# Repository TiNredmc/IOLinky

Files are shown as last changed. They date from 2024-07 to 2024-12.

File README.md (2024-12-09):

# IOLinky

IOLinky is an attempt to implement an open-source bare-minimum working IO-Link device.
This project is the part of the undergraduate Automation engineering Co-operative education project while working as R&D internship at Delta Electrnics (Thailand) PCL. From King Mongkut's Institute of Technology Ladkrabang (KMITL). 

**WARNING: THIS SOFTWARE IS NOT MEANT TO BE USED IN COMMERCIAL PRODUCT, I, THIPOK JIAMJARAPAN WILL NOT BE RESPONSIBLE FOR ANY FAILURES/MULFUNCTIONS CAUSED BY THE USE OF THIS SOFTWARE (OR ANY MATERIAL OF THIS PROJECT) IN THE COMMERCIAL PRODUCT, ESPECIALLY SAFETY-RELATED PRODUCT. USER WHO INSISTED TO USE THIS SOFTWARE IN COMMERCIAL PRODUCT WILL HAVE TO TAKE ALL THE RISK ON YOUR OWN. GOOD LUCK, YOU HAVE BE WARNED**

The example application of the IOLinky is the 24 to 5 VDC buck converter, with the feature of input and output monitoring plus Efuse (I2t) implementation.

The original goal of IOLinky is to build the bare-minimum IO-Link compatible device. But the software stack is endded up working quite well. This will soon shifted from a single-use code to the library-code approach. Contribution to project are appreciately welcome!

# Acknowledgement 

This project was made possible by the generous support from these great individuals.
 - **Mr. P. Haribabu**, RD Firmware engineer from **Delta Electronics (Thailand) PCL** for the internship opportunity and project supervision. 
 - **Mr. Steve Liang**, Technical engineer from **STMicroelectronics** for the IO-Link technical support. 
 - **Wurth Electronics (Thailand) Co., Ltd** for providing free component samples to be used in this project.  
 - **Assoc.Prof.Dr. Apinai Rerkratn** from Automation engineering department, school of engineering **KMITL**.

# General Info

- COM modes
    - Peak COM3 response time (L6362A + STM32F042) at **```51.2us```** 
	- Peak COM3 response time (L6362A + GD32E230F8 + New UART API) at **```33.0us```**
    - Cycle time is **```20.00ms```**
    - Supported all COM modes. But may have spec unmet
    - COM3 **SPEC MET✔️**  (IOLinky v1.0 only, for now)
    - COM2 **SPEC MET✔️**
    - COM1 **SPEC MET✔️**

- M-sequence types (Code-customizable)
    - ```M_TYPE_0``` in **Startup** and **Pre-operate** mode
    - ```M_TYPE_2_2``` or ```M_TYPE_2_V``` in **Operate** mode

- Page (Direct parameters)
    - Direct parameter 1 with master command for switching between operation mode
    - Read / Write the Direct parameter 2 is supported

- ISDU 
    - Read / Write system command (unused for now)
    - Basic mandatory info such as Product ID and Vendor ID
    - Process Data Input only (M_TYPE_2_2 and M_TYPE_2_V)

- Process Data
    - 16 Bit PD input with ```M_TYPE_2_2```
    - 8 octet PD input with ```M_TYPE_2_V``` (IOLinky v1.0)
    - PD output is not implemented at this time of writing but possible

# TODO
- Code separation as a standalone library

- M-sequence
    - Check Master's CKT

- ISDU
    - Vendor command for fun
    - Data storage feature
    
- Event
    - Implement event/diagnostic feature

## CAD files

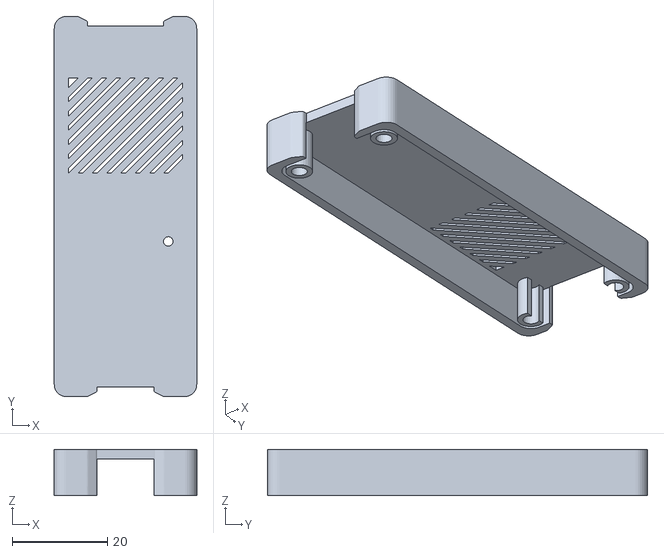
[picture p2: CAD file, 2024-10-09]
Hardware/IOLinky_V1.0/Mechanical/IOLinky_Top_HousingV1.2.stl
30.0 x 80.0 x 9.70

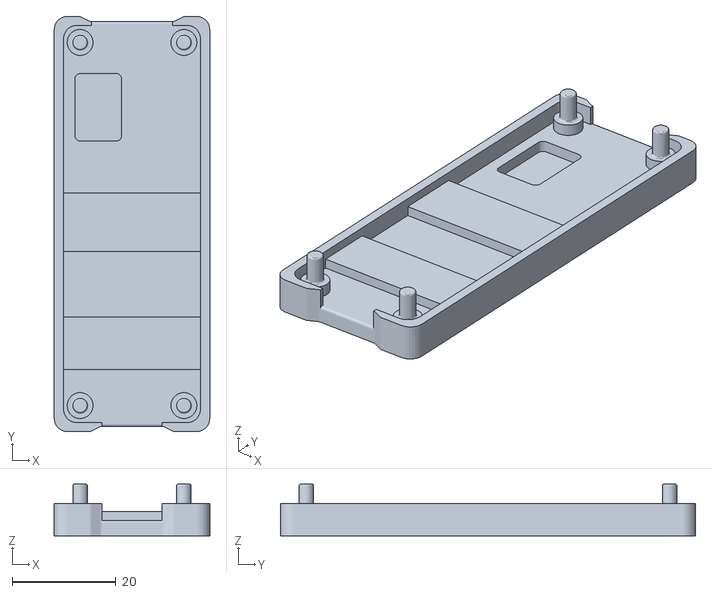
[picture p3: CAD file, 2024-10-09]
Hardware/IOLinky_V1.0/Mechanical/IOLinky_Bottom_HousingV1.2.stl
30.0 x 80.0 x 10.0

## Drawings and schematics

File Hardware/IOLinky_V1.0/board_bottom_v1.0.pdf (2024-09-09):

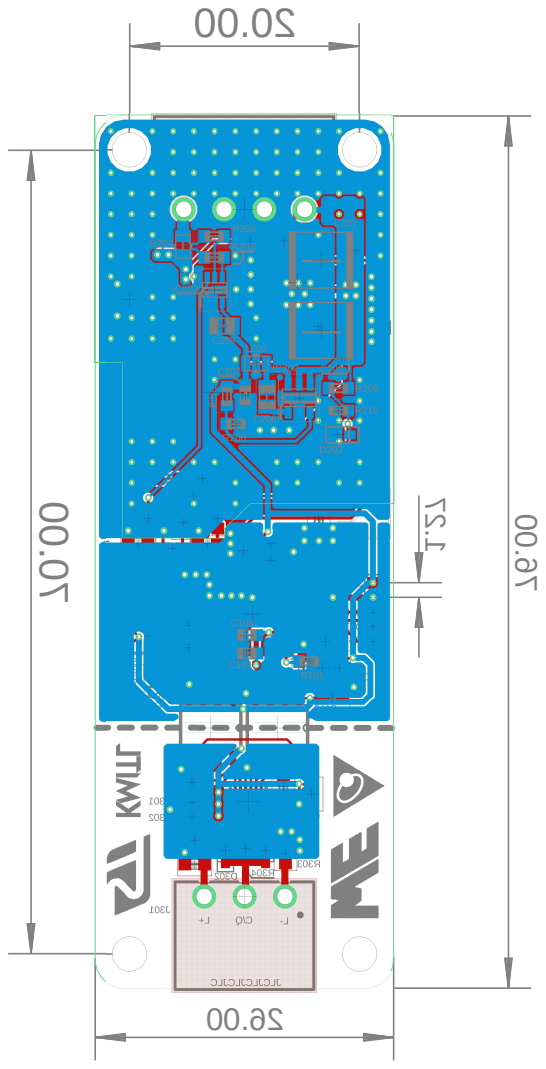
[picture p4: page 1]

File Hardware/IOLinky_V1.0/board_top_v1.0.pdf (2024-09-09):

20.00 70.00

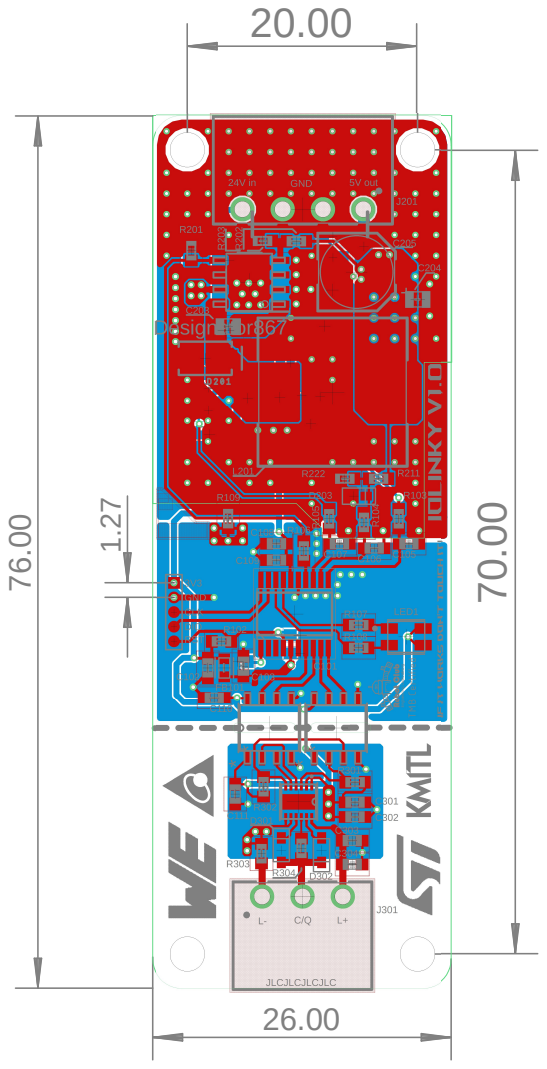
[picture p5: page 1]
Designator867 1.27

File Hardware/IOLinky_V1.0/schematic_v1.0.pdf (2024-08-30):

600R 10k

# FB101 R¹⁰¹

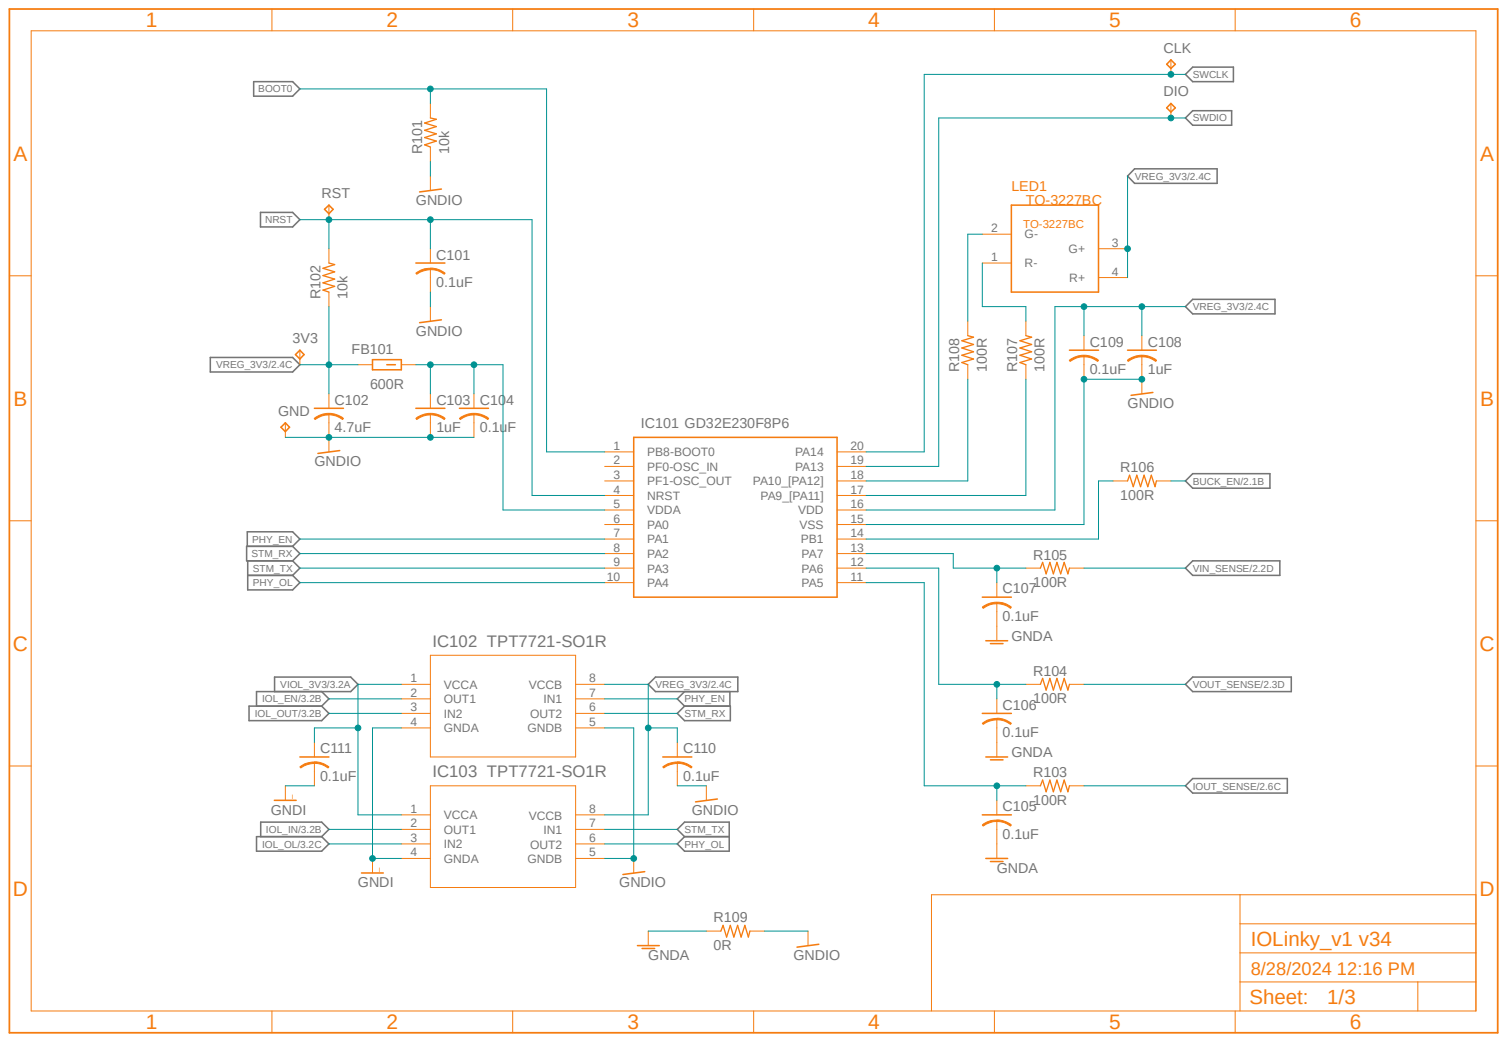
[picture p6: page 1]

A

A

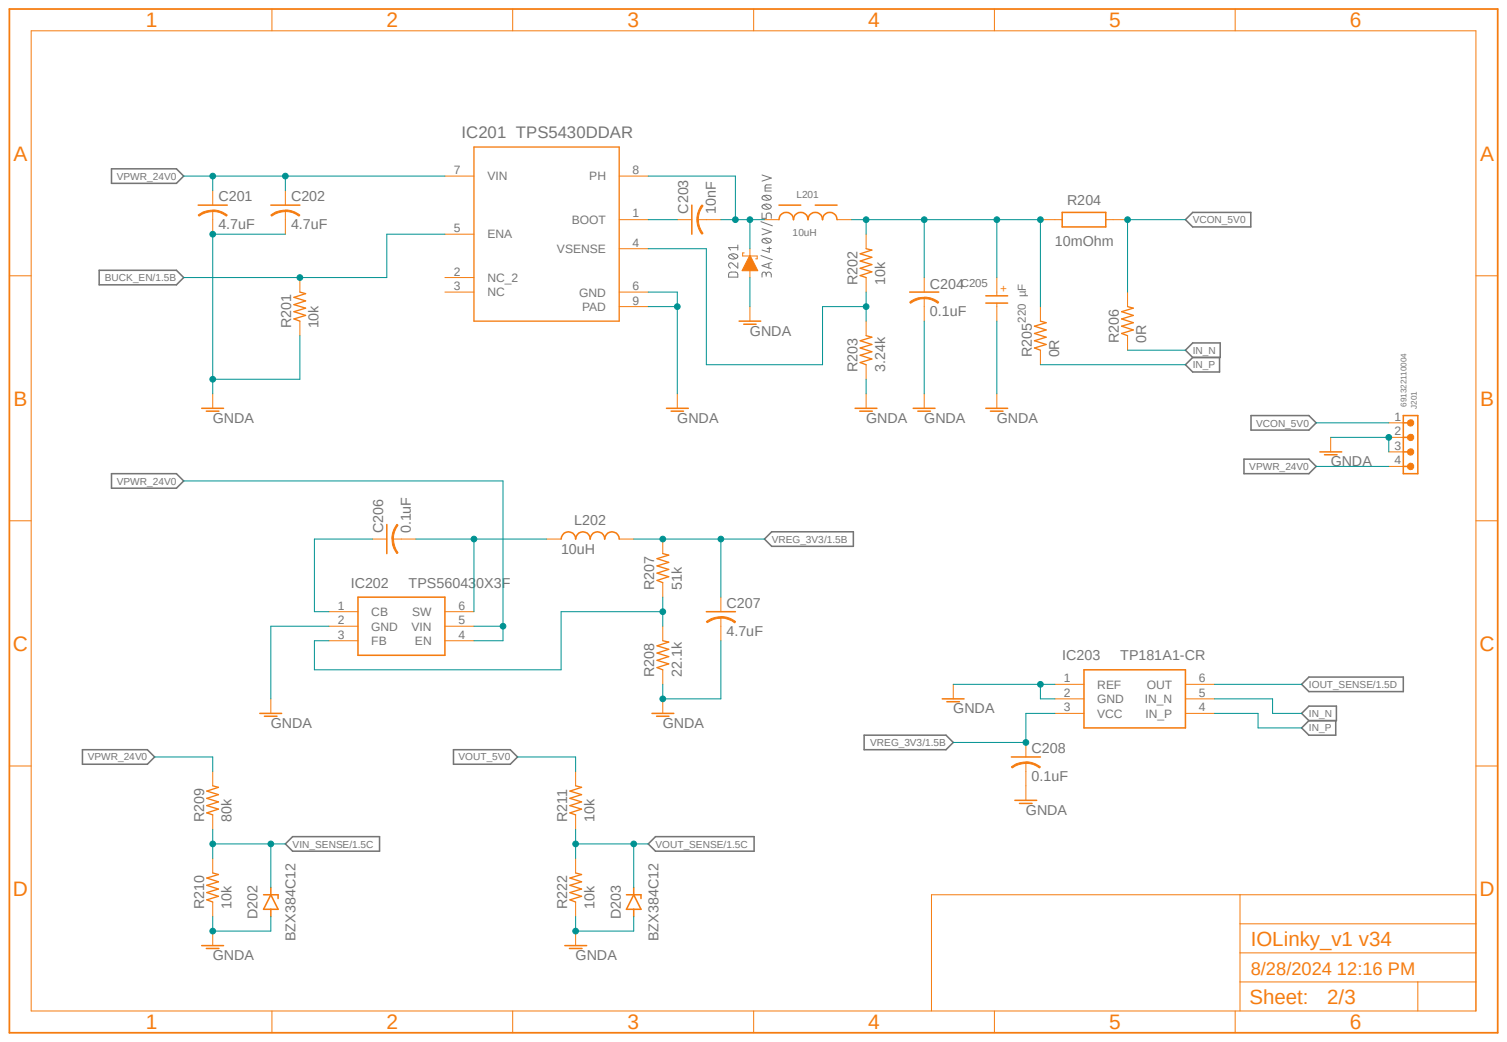
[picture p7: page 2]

A

A

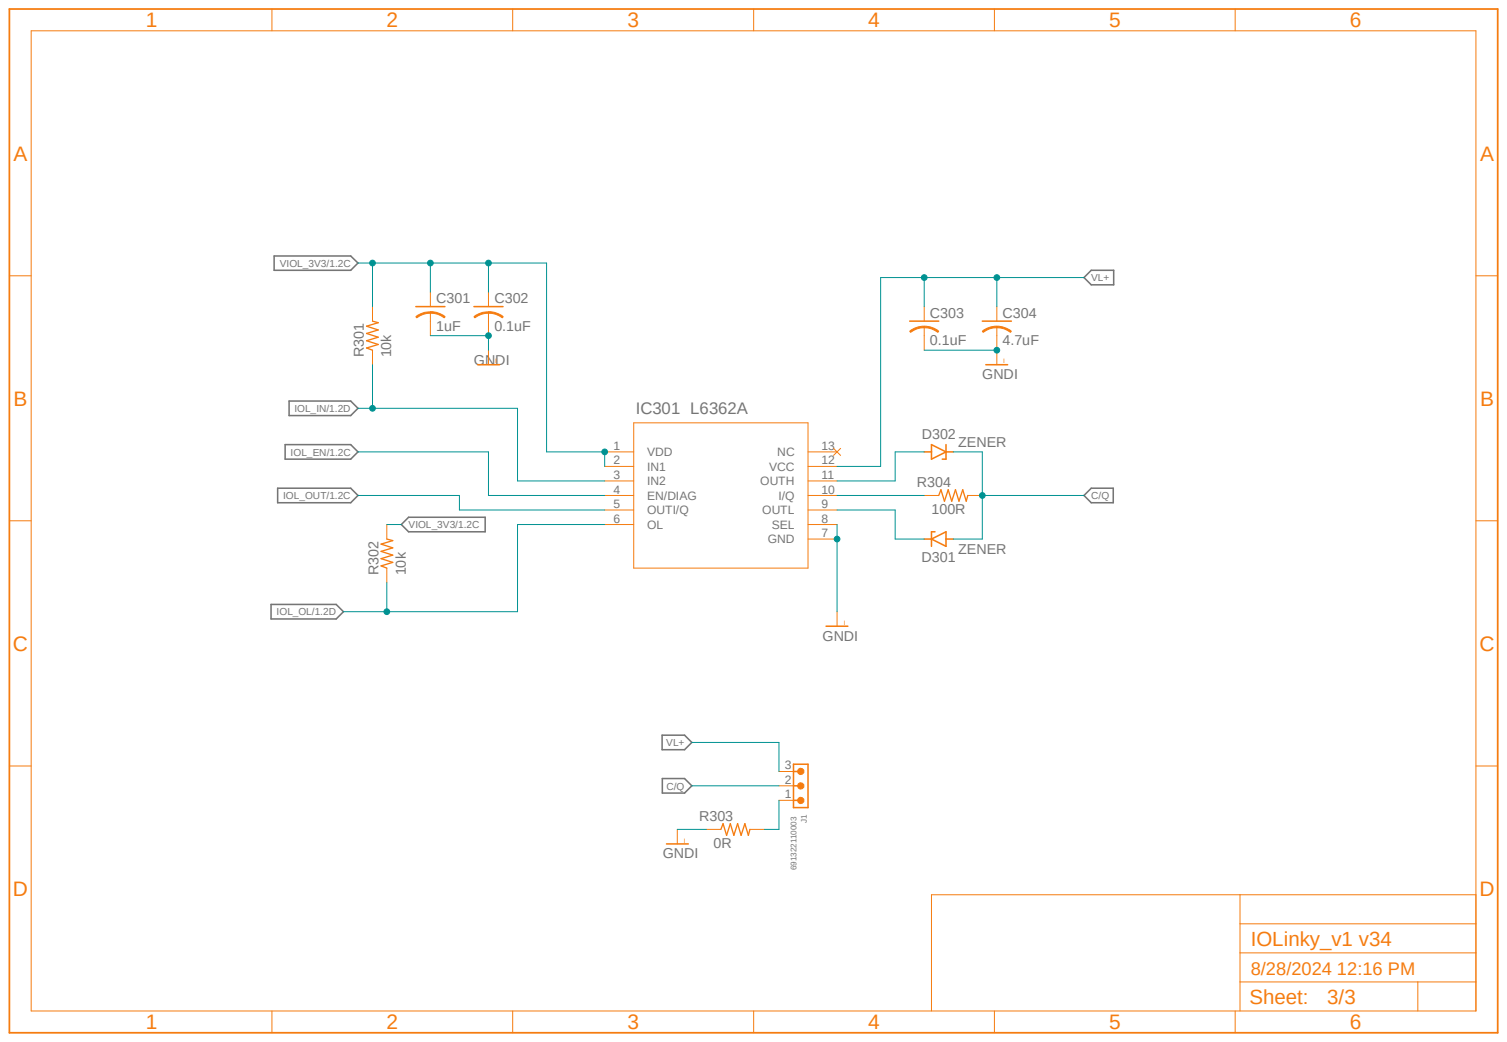
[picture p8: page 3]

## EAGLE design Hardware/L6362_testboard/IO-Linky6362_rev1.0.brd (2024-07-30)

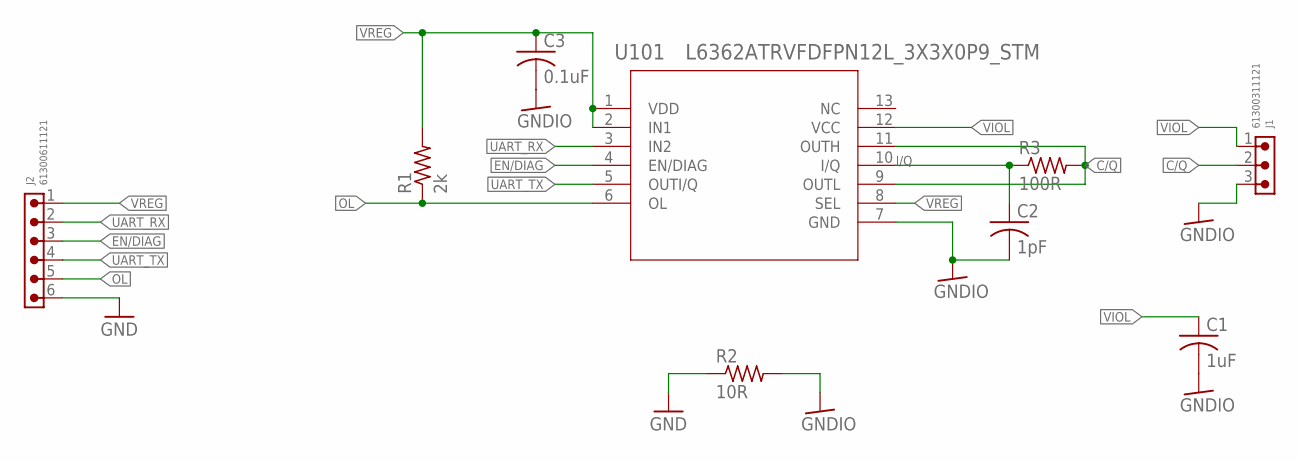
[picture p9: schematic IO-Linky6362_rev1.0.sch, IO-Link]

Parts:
C1: 1uF; C0603K
C2: 1pF; C0603K
C3: 0.1uF; C0603K
J1: 61300311121
J2: 61300611121
R1: 2k; R0603
R2: 10R; R0603
R3: 100R; R0603
U101: L6362ATRVFDFPN12L_3X3X0P9_STM; VFDFPN12L_3X3X0P9_STM

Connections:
C/Q: J1.2, R3.2, U101.9 (OUTL), U101.11 (OUTH)
EN/DIAG: J2.3, U101.4 (EN/DIAG)
GND: J2.6, R2.1
GNDIO: C1.2, C2.2, C3.2, J1.3, R2.2, U101.7 (GND)
I/Q: C2.1, R3.1, U101.10 (I/Q)
OL: J2.5, R1.1, U101.6 (OL)
UART_RX: J2.2, U101.3 (IN2)
UART_TX: J2.4, U101.5 (OUTI/Q)
VIOL: C1.1, J1.1, U101.12 (VCC)
VREG: C3.1, J2.1, R1.2, U101.1 (VDD), U101.2 (IN1), U101.8 (SEL)

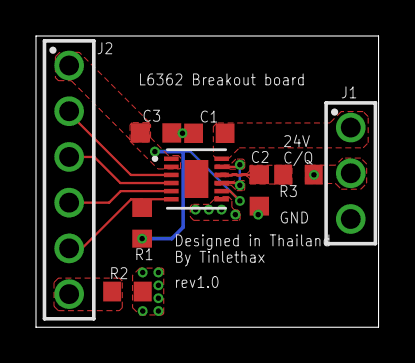
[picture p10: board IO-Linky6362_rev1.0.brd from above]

Board: 2 copper layers, 19.0 x 16.2 mm, 9 parts (0 on the bottom side), 10 nets.

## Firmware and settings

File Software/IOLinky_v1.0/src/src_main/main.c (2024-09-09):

// IO-Linky V1.0 
#include "main.h"

typedef struct myFunctions{
	void (*testA)(void);
	void (*testB)(uint8_t input);
}myFunctions;

void testAFunct(){

}

void testBFunct(uint8_t input){

}

myFunctions testAPI = {
	testAFunct,
	testBFunct
};

void NMI_Handler(void){


}

void HardFault_Handler(void){
	while(1);
}


int main(){
	app_initIO();

	testAPI.testA();
	
	while(1){
		app_runner();
	}


}

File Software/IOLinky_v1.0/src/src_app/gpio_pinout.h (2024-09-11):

#ifndef GPIO_PINOUT_H
#define GPIO_PINOUT_H

// Port A
#define IOL_mon				0
#define EN_pin				1
#define USART2_RX			2
#define USART2_TX			3
#define OL_pin				4

#define Isense_pin		5
#define V5sense_pin		6
#define V24sense_pin	7

#define RedLED_Pin		9
#define GreenLED_Pin	10

// Port B
#define ENBuck_Pin		1

#endif

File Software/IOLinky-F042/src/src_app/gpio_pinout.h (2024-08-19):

#ifndef GPIO_PINOUT_H
#define GPIO_PINOUT_H

// Port A
#define EN_pin			1
#define USART2_TX		2
#define USART2_RX		3
#define OL_pin			4

#define Isense_pin	5
#define V5sense_pin	6
#define V24sense_pin	7

// Port B
#define IOL_mon			1

#endif

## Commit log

2024-07-10 Updated SPI FSM
2024-07-10 Changed Blinking LED to LED2 (Green) and shorten the breathing pattern.
2024-07-23 Big updates. - Device parameter page 1 data moved to the upper layer (to the Application layer). - Added communication timeout, fall back to STARTUP mode after certain period of time if no comm. - Ad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
2024-07-25 Typo fix and minor bugfix
    Fixed some syntax error and a minor bug.
    Calling spi_l6364FastWriteFF with count > 0x0F would have resulted in return 0 (aka 0 bytes remaining to transmit)
    [spi.c]
2024-07-25 Moved #include "Systick_delay.h" from spi.c to spi.h
    Following mantainer coding standard
2024-07-26 Process Data will only update when necessary to prevent weird bug. IO-Link timeout reset depends on ISDU Flow control Idle command.
2024-07-30 Solved the periodically missing PD data. Added process data write for later use.
    [iol_al.c]
2024-07-30 Update to keep track.
2024-07-30 Added schematic and board file for L6362 breakout board(Experiment).
    [IO-Linky6362_rev1.0.brd, IO-Linky6362_rev1.0.sch]
2024-08-14 EN pin of L6362A will be a forced output instead of Pull-up OD.
2024-08-14 Fixed the missing uart bit and TX switching too early issue.
    [usart.c]
2024-08-19 function names are now startin with usart. Also preparing for USART DMA TX.
2024-08-19 Added ADC driver.
2024-08-19 PD is not the read value from ADC.
2024-08-19 updated pin out.
2024-08-19 updated function name according to update to usart driver.
2024-08-19 Update ADC read demo every 20ms.
2024-08-27 Added PDF files of first prototype hardware
2024-08-27 Documents for GD32E230F8 that will be used in the first prototype.
2024-08-28 Keep track of the project file.
2024-08-28 corrected baud rate on 72MHz APB clock.
    [usart.c]
2024-08-28 Currently using HXTAL, will revert back to IRC8M soon. As the first prototype doesn't have XTAL.
2024-08-28 Corrected DMA clock bitmask and ADC data pointer before DMA.
    [adc.c]
2024-08-28 Added ADC. TODO: change message type and wrote the buck converter monitoring system.
2024-08-30 updated schematic of IOLinky V1.0.
2024-08-30 Updated the LED status to be used with TIMER0 PWMM.
2024-08-30 Use the slowest sample rate. ADC startup delay is now wokring with -O balanced.
2024-08-30 Keep track of the project configuration.
2024-08-30 Switch back to IRC8M instead of HXTAL as the actual board doesn't use xtal. Will add xtal later if the board need to respin.
2024-08-30 Vout undervoltage will only notify when buck converter is commanded to be on.
2024-09-02 Changed ADC buffer pointer type to 16bit.
2024-09-02 Added peak current along side the Nominal High and Short circuit.
2024-09-02 Changed ADC buffer pointer type and few changes to the FSM.
2024-09-02 LED PWM is now working.
2024-09-02 LED status is now breathing.
2024-09-09 Removed the unused pin and changed speed of LED task.
2024-09-09 reset index at init of L6362A.
    [iol_l6362.c]
2024-09-09 Board view PDF update and added Fusion 360 archive file.
2024-09-09 Added fault indicator LED mode.
2024-09-09 Only allows power on when Vin is ok.
2024-09-10 Updated Input voltage ADC conversion factor to 0.00747.
2024-09-10 temporary changes the resistor divider calculation value. Need more investigation.
2024-09-10 Corrected the F_CPU value used for Systick. As well as LED task period.
    [app_device_impl.c]
2024-09-11 - API changes to UART driver - to allow the response time in COM3 mode from >43us MAX to just 33.0us MAX.
2024-09-13 Updated Logic of PSU, Efuse is now working properly. TODO : - Efuse setting via IO-Link ISDU - Calibration value and compenstation.
2024-09-20 Updated IODD to accomodate for the parameter and calibrations through ISDU.
2024-09-20 Huge update. [PSU and IO-Link side] - PSU power on/off, Efuse Amp Trip, Period Hold and ADC calibration value are now accessible via ISDU (some RW, some RO, some WO). - Added app_nvm for retrieve and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
    [app_device_impl.c, app_monitoring.c, app_nvm.c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]
2024-09-20 New linker script to reserve the upper portion of flash memory for calibration and efuse data.
2024-09-23 Output current good indicator only works in PSU on mode.
2024-09-27 Moved LED from the iol_pl to user app.
2024-10-09 Added the mechanical design for the IOLinky V1.0.
    [IOLinky_Bottom_HousingV1.2.stl, IOLinky_Top_HousingV1.2.stl]
2024-10-16 Fixed the Short circuit flag.
    [app_monitoring.c]

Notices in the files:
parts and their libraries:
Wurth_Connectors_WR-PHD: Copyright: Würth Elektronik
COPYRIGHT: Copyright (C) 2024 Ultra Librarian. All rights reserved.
